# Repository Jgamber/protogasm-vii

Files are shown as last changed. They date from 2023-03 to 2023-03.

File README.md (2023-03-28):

# Protogasm VII
Version two includes code refactoring, and bug fixes.
I have also fixed up the STL models.
- Added encoder knob model for printing
- Cleaned up SCAD Code
- The print time has been reduced by about half
- Removed the screw holes (Lid snaps on now)
- Made the roof/floor less thick
- Removed extra lip around encoder knob hole
- Arduino fits better
- Pressure sensor fits better, USB and power jack holes removed, as they are not used in the case.

Software and hardware for Arduino-based orgasm prediction / detection ... on protoboard!

The nogasm is an amazing toy.  I wanted to make something easier to hack and more accessible to the homebuilder.  Fortunately headcrabned was kind enough to open source the whole thing.

I ported it the Arduino Uno, and hacked around on perfboard until I had it working.  It works great and only requires a handful of readily available through-hole components.

Some aspects have been simplified compared to the original electronics:
* The DIP switches have been eliminated.  Options are configured in the source instead.
* The RGB backlit rotary encoder has been replaced with a more common unlit one.  The mode is still visible on the LED ring.
* It has more LEDs!  NeoPixel Rings with 24 LEDs are the right size for the project.

## Getting started

* [RTFM](User%20Guide.pdf)

* [Buy the parts](BOM.md)
* [Build the control board](pcb/)
* Flash the Arduino with the [Protogasm VII Code](code/protogasm_vii.ino)
* [Print the case](case/)
* [Build the vibrator](vibrator/)
* *TODO* Setup the plug

#### Fine print
This work is licensed under a Creative Commons Attribution-NonCommercial 4.0 International Licence, available at http://creativecommons.org/licenses/by-nc/4.0/.

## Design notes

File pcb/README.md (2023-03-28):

# Circuit Assembly

protogasm_layout.png shows how I build my boards - the wire goes into the hole
next to a component's leg and is then bent down to meet the leg.

Cut the mounting tabs off of the rotary encoder and install it at the center of
the board.  The center pin should point at Arduino pin 12.  Squeeze the pins
together slightly so they go into columns 8 and 13.

The trimpot goes with its center leg directly connected to the AREF hole.

The MOSFET goes on the back of the board on column 12.  The center pin should be
aligned with VIN.

The pressure sensor is installed with the pins bent the wrong way.  If you
install it the right way there isn't enough clearance for the hose barb.  Pin 1
(notched) goes in column 9, two holes up from the SCL pin.  The mounting ears
need to be removed to provide clearance for the USB and power connectors on the
Arduino.  I simply clipped them off with wire cutters.

Install the remaining passives and wiring.

Break away some pin headers to the correct lengths and install them onto the shield (perfboard)
with the short end poking above. Mount it into the Arduino, and solder the top of each pin.

The Neopixel Ring is installed/elevated on three .100 breakaway header pins for PWR, GND,
and OUT.  Do not install a pin header on IN because it will short against the USB port. (The perfboard
touches the metal on the Arduino's USB port.) I soldered a wire to IN and have the other end simply fit
into pin 10, so I can still remove the ring when needed.
The pins need to tilt slightly so place the Neopixel Ring on them to hold them
in the correct orientation before soldering them to the board.

The power out to the motor is taken from either side of the diode.  I made a
short cable with a female power jack DC connector and soldered it to the pins.
Then on the other end of the vibrator a male power jack adapter.

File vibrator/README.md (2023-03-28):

The "handle.STL" and "head.STL" are the main parts of the vibrator, ready for
3D printing.

The vibrator is made from a Mabuchi RS-555PH motor, with an eccentric mass
pressed onto the shaft. These can be purchased pre-assembled, or built from the
motor and some .88" to 1" diameter cylindrical brass stock.

The vibrator case is compatible with attachments designed for the Hitachi Magic
Wand. The motor is press-fit or glued into the two halves of the case.

* Print the case.
* Install an eccentric weight on the motor's shaft if it does not have one already.
* Solder or crimp wires to the motor.
* Pull wires through the small hole in the side of the housing.
* Press firmly to assemble.

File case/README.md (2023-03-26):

Print the case in a light color so that the LEDs show through.

Place the Arduino in the case, and a power jack adapter on the right side of it
inside of the case, and super glue or hot glue it in place. The center hole is for the
pressure sensor, the right hole is for the external power jack (NOT the Arduino's built in)

For the vibrator you can make it easily detachable by using a male/female combo of 
adapters from the Amazon link in the BOM. For example: attach a male adapter to wires coming
out of the vibrator, then solder a female adapter to VIN and GND in the case.

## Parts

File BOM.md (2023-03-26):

| Part | Value | Description | Price  | Mouser | Link |
| ---- | --- | --- | --- | --- | --- |
| ACC  | Arduino UNO | ELEGOO UNO R3 Board ATmega328P | $16.99 | | https://www.amazon.com/dp/B01EWOE0UU  |
| ACC  | Wire Kit | 22 Gauge Wire Solid Core Hookup Wires | $12.99 | | https://www.amazon.com/dp/B088KQFHV7  |
| ACC  | Pin Headers | Male Header Pin, 40 Pin Header Strip | $4.99  | | https://www.amazon.com/dp/B07PKKY8BX  |
| ACC  | DC Adapter | DC 12V 5A Power Supply | $9.89  | | https://www.amazon.com/dp/B08C594VNP  |
| ACC  | DC Cable | DC Power Cable 12V 5A Plugs Male Female | $9.29  | | https://www.amazon.com/dp/B07C7VSRBG  |
| | | | | | |
| VBRT | Vibrator Motor | Mabuchi RS-555 12VDC Motor | $22.95 | | https://www.ebay.com/itm/274750329308 |
| | | | | | |
| PLUG | Air line | Air line 5/32" with Tee | $21.37 | | https://maustec.io/products/replacement-air-line |
| | | | | | |
| -- | NEOPIXEL RING  | Adafruit 24 RGB LED Neopixel Ring | $18.18 | | https://www.amazon.com/dp/B00K9M3WXG  |
| U1 | ARDUINOR3PERF  | Electronics Salon Arduino Uno R3 Perfboard | $14.00 | | https://www.amazon.com/dp/B01J1KM3RM  |
| C1 | 0.1u | CAPACITOR, American symbol | $9.99  | 80-C320C104K5R | https://www.amazon.com/dp/B094HRK8QX  |
| D1 | 1N5818-B | 1.0A SCHOTTKY BARRIER RECTIFIER | $9.99  | 512-1N5818 | https://www.amazon.com/dp/B07YG8K1R9  |
| PS1  | MPX5050GP | Integrated Silicon Pressure Sensor | $53.70 | 841-MPX5050GP | https://www.amazon.com/dp/B005T5KNDK  |
| Q1 | FQP30N06L | Power MOSFET N-Channel | $8.89  | 512-FQP30N06L | https://www.amazon.com/dp/B07WHSD3GJ  |
| R1 | 100K | RESISTOR, American symbol | $12.99 | 660-MF1/4DC1003F | https://www.amazon.com/dp/B07P3MFG5D  |
| SW1  | Rotary encoder | Rotary Encoder w/ switch (EC12D or similar)  | $11.99 | 652-PEC11R-4115F-S18 | https://www.amazon.com/dp/B0197X1UZY  |
| TM1  | 10K | Trimmer Potentiometer | $7.16  | 652-3306P-1-103 | https://www.amazon.com/dp/B00SWK15KE  |

The whole assembly (Including Arduino, accessories, etc) will cost you about **$240.0**

If you already have an Arduino, pin headers, etc, you can get this quite a bit cheaper.

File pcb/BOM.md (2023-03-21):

| Part | Value | Description | Price  | Mouser | Link |
| ---- | --- | --- | --- | --- | --- |
| ACC  | Arduino UNO | ELEGOO UNO R3 Board ATmega328P | $16.99 | | https://www.amazon.com/dp/B01EWOE0UU  |
| ACC  | Wire Kit | 22 Gauge Wire Solid Core Hookup Wires | $12.99 | | https://www.amazon.com/dp/B088KQFHV7  |
| ACC  | Fun Kit | ELEGOO Upgraded Electronics Fun Kit | $17.99 | | https://www.amazon.com/dp/B09YRJQRFF  |
| ACC  | Vibrator Motor | Mabuchi RS-555PH 12VDC Motor | $9.60  | | https://www.ebay.com/itm/285149714808 |
| ACC  | DC Adapter | DC 12V 5A Power Supply | $11.99 | | https://www.amazon.com/dp/B01GEA8PQA  |
| | | | | | |
| PLUG | Air line | Air line 5/32" with Tee | $21.37 | | https://maustec.io/products/replacement-air-line |
| | | | | | |
| -- | NEOPIXEL RING  | Adafruit 24 RGB LED Neopixel Ring | $18.18 | | https://www.amazon.com/dp/B00K9M3WXG  |
| U1 | ARDUINOR3PERF  | Electronics Salon Arduino Uno R3 Perfboard | $14.00 | | https://www.amazon.com/dp/B01J1KM3RM  |
| C1 | 0.1u | CAPACITOR, American symbol | $9.99  | 80-C320C104K5R | https://www.amazon.com/dp/B094HRK8QX  |
| D1 | 1N5818-B | 1.0A SCHOTTKY BARRIER RECTIFIER | $9.99  | 512-1N5818 | https://www.amazon.com/dp/B07YG8K1R9  |
| PS1  | MPX5050GP | Integrated Silicon Pressure Sensor | $53.70 | 841-MPX5050GP | https://www.amazon.com/dp/B005T5KNDK  |
| Q1 | FQP30N06L | Power MOSFET N-Channel | $8.89  | 512-FQP30N06L | https://www.amazon.com/dp/B07WHSD3GJ  |
| R1 | 100K | RESISTOR, American symbol | $12.99 | 660-MF1/4DC1003F | https://www.amazon.com/dp/B07P3MFG5D  |
| SW1  | Rotary encoder | Rotary Encoder w/ switch (EC12D or similar)  | $11.99 | 652-PEC11R-4115F-S18 | https://www.amazon.com/dp/B0197X1UZY  |
| TM1  | 10K | Trimmer Potentiometer | $7.16  | 652-3306P-1-103 | https://www.amazon.com/dp/B00SWK15KE  |

The whole assembly (Including Arduino, accessories, etc) will cost you about **$275.0**

If you already have an Arduino, pin headers, etc, you can get this quite a bit cheaper.

The "Electronics Fun Kit" contains many unnecessary parts, but it includes pin headers, and extra
resistors and useful parts. There is also a 10k trimpot you can use (I used this, but had to cut a hole
in the lid because it is too tall.)

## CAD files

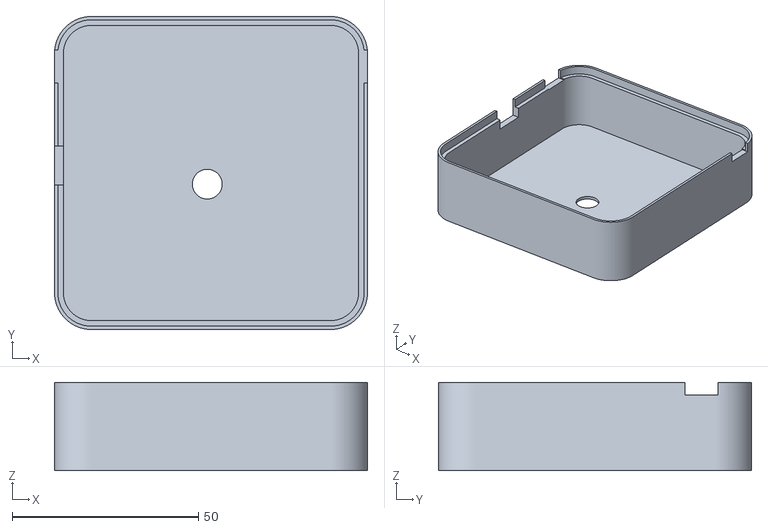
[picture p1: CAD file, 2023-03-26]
case/stl/protogasm_lid.stl
84.1 x 84.1 x 23.7

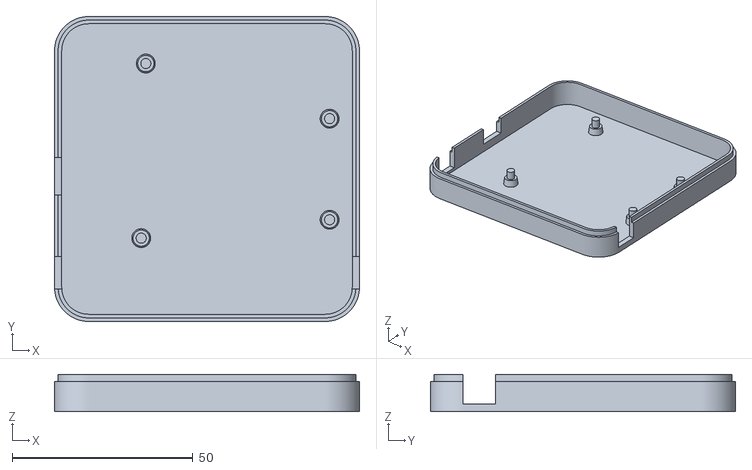
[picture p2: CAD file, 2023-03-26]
case/stl/protogasm_base.stl
84.3 x 84.3 x 10.3

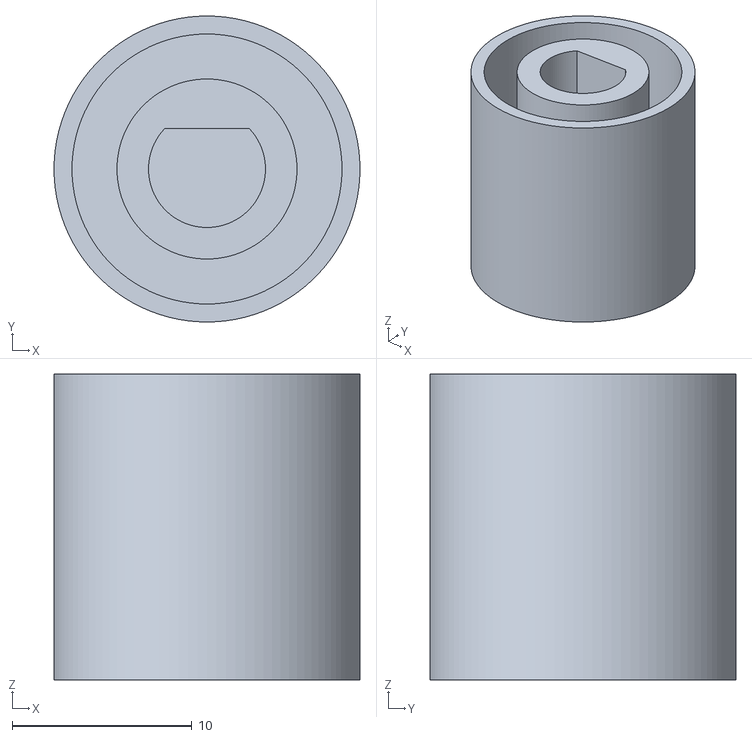
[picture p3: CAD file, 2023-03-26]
case/stl/knob.stl
17.0 x 17.0 x 17.0

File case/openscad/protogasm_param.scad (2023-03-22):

//  ----------------------------------------------------------------------- LICENSE
//  This "3D Printed Case for Arduino Uno, Leonardo" by Zygmunt Wojcik is licensed
//  under the Creative Commons Attribution-ShareAlike 3.0 Unported License.
//  To view a copy of this license, visit
//  http://creativecommons.org/licenses/by-sa/3.0/
//  or send a letter to Creative Commons, PO Box 1866, Mountain View, CA 94042, USA.


//------------------------------------------------------------------------- SHARED PARAMETERS
$fn=100; // resolution

circleD = 21; // round corner circle diameter
roundR = circleD/2; // round corner circle radius
triangleH = (sqrt(3)*(circleD))/2; // triangle height to calculate other variables

layerHeight = 0.25; // some variariables are multiple of layer height and width
layerWidth = 0.5;

verConnectionHoleR = 1.2; // screw thread hole radius
screwHead = 6; // screw head hole diameter

gap = layerHeight/2;

floorHeight = 1.0; // 6*0.25 layer + 0.3 first layer

height = 20.6; // case height
innerHeight = height - floorHeight*2;

pillarSize = 3.0; // corner pillar size

// dimensions of minkowski's inner square
// these are NOT case dimensions
// to calculate external case dimesions add 2 * roundR
// 55.3 + (2*10.5) = 76.3
width = 65.3;
wide = 65.3;

blockLockSize = 2; // middle connection lock size

// side cutting panels size
sidePanelXWidth = wide;
sidePanelYWidth = width;

// prints dimensions of the case
echo("width", width + roundR*2); // total width
echo("wide", wide + roundR*2); // total wide

// UNO PCB dimensions
pcbWide=43.3;
pcbLenght=68.58;
pcbHeight=1.64;
usbHolePosition=38.1;
usbHeight=10.8 + 2;
usbWide=11.43 + 2;
powerJackPosition=7.62;
powerJackWide=8.9;
powerJackHeight=10.8 + 2;

pcbPositionX = (width/2 + roundR - layerWidth*7 - gap*4)-7;
pcbPositionZ = 2.5;

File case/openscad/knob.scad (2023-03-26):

/*
 Simple knob for rotary encoder.
*/
$fn = 100;

height = 17;
diameter = 17;
thickness = 2;
push_btn = 6;
d_shaft_diameter = 6.5;
d_width = 1;


// Outer wall
difference() {
    // ADD
    union() {
        cylinder(height, diameter / 2, diameter / 2);
    }

    // SUBTRACT
    union() {
        translate([0, 0, 1])
        cylinder(height + 0.01, (diameter / 2) - (thickness / 2), (diameter / 2 )- (thickness / 2));
    }
}

// Inner wall
difference() {
    // ADD
    union() {
        dia = d_shaft_diameter - 1.5;
        cylinder(height, dia, dia);
    }
    
    // SUBTRACT
    union() {
        translate([0, 0, push_btn + 0.01])
        cylinder(height - push_btn, d_shaft_diameter / 2, d_shaft_diameter / 2);
    }
}
  
    

// Add shaft holder
union() {
    translate([-d_shaft_diameter / 2, d_shaft_diameter / 2 - d_width, 0])
    cube([d_shaft_diameter, d_width, height]);
}

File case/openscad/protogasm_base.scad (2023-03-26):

//  ----------------------------------------------------------------------- LICENSE
//  This "3D Printed Case for Arduino Uno, Leonardo" by Zygmunt Wojcik is licensed
//  under the Creative Commons Attribution-ShareAlike 3.0 Unported License.
//  To view a copy of this license, visit
//  http://creativecommons.org/licenses/by-sa/3.0/
//  or send a letter to Creative Commons, PO Box 1866, Mountain View, CA 94042, USA.


include <protogasm_param.scad>

//------------------------------------------------------------------------- MODULES
module pcbLeg() {
	translate([0, 0, 0])
	difference() {
		cylinder(h = floorHeight + pcbPositionZ, r1=5.5/2, r2 = 4.5/2);
	}
}


//------------------------------------------------------------------------- MAIN BLOCK
difference() {
	// ADD
	union() {
		// Add Base
		linear_extrude(height = height/2, convexity = 10)
		minkowski() {
			square([width, wide], center = true);
			circle(roundR-1);
		}
	}

	// SUBSTRACT
	union() {
		// Lift floor height
		translate([0, 0, floorHeight]) {
			// Cut Base hole
			linear_extrude(height = height/2, convexity = 10)
			minkowski() {
				square([width, wide], center = true);
				circle(roundR - pillarSize);
			}

			// Cut upper block lock
			difference() {
				translate([0, 0, height/2 - floorHeight - blockLockSize]) {
					cylinder(h = blockLockSize+gap, r=width);
				}

				translate([0, 0, height/2 - floorHeight - blockLockSize - gap*2]) {
					linear_extrude(height = blockLockSize+gap*4, convexity = 10)
					minkowski() {
						square([width, wide], center=true);
						circle(roundR - layerWidth*4);
					}
				}
			}

			// Cut x panels 
			for (i = [0 : 180 : 180])				
			rotate([0, 0, i])
			translate([width/2 + roundR - pillarSize/2 - layerWidth*7, 0, 0]) {
				// Cut X panel hole
				translate([0, 0, height/2])
				cube([pillarSize, sidePanelXWidth, height], center=true);
			}

			// Cut Y panels 
			for (i = [90 : 180 : 270])
			rotate([0, 0, i])
			translate([wide/2 + roundR - pillarSize/2 - layerWidth*7, 0, 0]) {
				// Cut Y panel hole
				translate([0, 0, height/2])
				cube([pillarSize, sidePanelYWidth, height], center=true);
			}
			
            // Cut access holes
			// translate to pcb position
			translate([-pcbPositionX-7, -pcbWide/2-5, pcbPositionZ + pcbHeight]) {
                 // Cut pressure sensor hole
				translate([0, usbHolePosition - usbWide, (usbHeight-2)/2])
				cube([10, usbWide-3, usbHeight], center=true);
                
                // Cut power in hole
                translate([0, -2, (powerJackHeight-6)/2])
                cube([10, powerJackWide, powerJackHeight], center=true);
                
                // Cut power out hole
                translate([pcbLenght + 10, -2, (powerJackHeight-6)/2])
                cube([10, powerJackWide, powerJackHeight], center=true);
			}
		}
	}
}

//------------------------------------------------------------------------- ADD PCB LEGS
// Translate to pcbPositionX	
translate([-pcbPositionX, -pcbWide/2, 0])
difference() {
    // ADD
	union() {
		// Add pcb legs
		for(i=[ [13.97, 2.54, 0], 				
     	    	[15.24, 50.8, 0],
          		[66.04, 35.56, 0],
          		[66.04, 7.62, 0] ]) {
	    		translate(i)
	    		pcbLeg();
		}

		// Add pcb holders
		for(i=[ [13.97, 2.54, 0],
     	    	[15.24, 50.8, 0],
          		[66.04, 35.56, 0],
     	    	[66.04, 7.62, 0] ]) {
			translate(i)
			cylinder(h=floorHeight+pcbPositionZ+3.0, r=1.4);
		}
	}
}

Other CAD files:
case/openscad/protogasm_lid.scad

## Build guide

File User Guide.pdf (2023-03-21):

## Nogasm User Guide

Basic Usage

1. Plug the motor into the right power jack.
2. Plug the power supply into the left power jack.
3. Fit the pressure tubing onto the barb fitting between the power jacks.
4. Connect an inflation bulb and inflatable butt plug to the pressure tubing as shown:

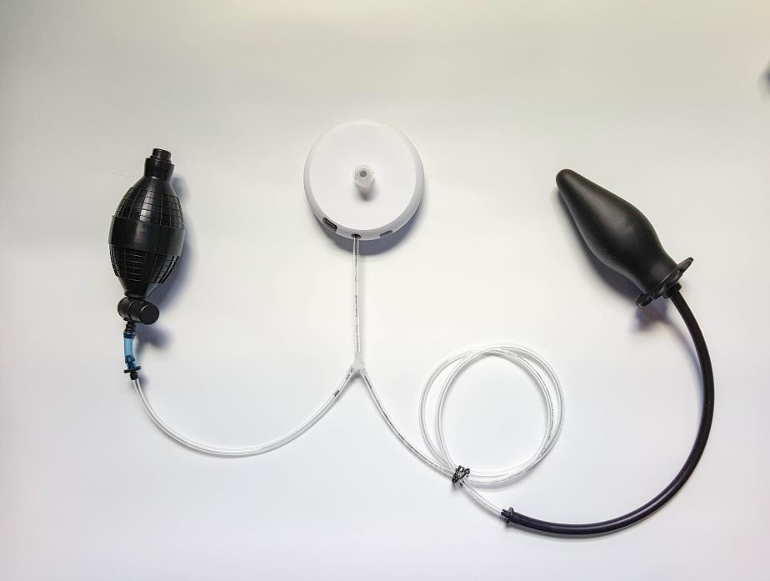
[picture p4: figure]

5. Nogasm detects approaching orgasms from pressure changes in an inflatable butt plug, so to use the edging feature, a user has to wear an at least slightly inflated plug.
6. Set up the vibrator for effective stimulation. Any common “Hitachi Magic Wand” attachment is compatible. If using rope to hold the vibrator in place, the loop in the back, and ridge behind the head of the vibrator can help keep it secure.
7. With the Nogasm on, turn the knob clockwise to check that the vibrator is working. Voluntarily clenching on the inflated plug should show some activity on the LED display at this point.
8. Press the knob once to enable the automated edging mode. The vibrator will slowly ramp up to its maximum speed.
9. The biggest key to a successful edging session is the edging sensitivity setting. Turn the knob clockwise to increase the sensitivity to maximum, and the display will turn from green to red, indicating that the user is too close to orgasm, and the vibrator will turn off temporarily.

10.From there, decrease the sensitivity slowly until you find the correct setting where the vibrator remains on just until the user is close to orgasm. Too high of a sensitivity will keep users from getting very close to orgasm at all, and too low of a sensitivity will allow the vibrator to stay on long enough for a user to cum. Ideal settings vary from person to person, and with different styles of inflatable plugs. If at any point a user is too close to orgasm, the knob can be pressed to immediately turn off the vibrator, and return to manual mode.
11.Finally, the included vibrator is relatively powerful, and lower speeds can feel better than 100% speed. To keep the vibrator at the best feeling speed in automatic mode, press the knob down for 1 second to enter the “Peak Speed” settings menu, which will change the display to all green. Rotating the knob will adjust the maximum speed that the edging mode will ramp up to, and drive the vibrator at that speed to demonstrate. By default, the maximum is set 70%. Long press one more time to return to manual mode.

Control

The Nogasm has one knob that can be rotated or pressed. Pressing the knob will change modes. Each mode illuminates the knob in a specific color, and uses the knob rotation to adjust different settings:

Mode | Knob Color | Knob rotation adjusts:
Manual | Red | Vibrator speed
Automatic Edging | Blue | Edging Sensitivity
Adjust Peak Speed | Green | Maximum vibrator speed in edging mode
Show Pressure Reading | White | [nothing]

Short presses cycle between manual control mode, and automatic edging mode. Long presses (between ½ and 3 seconds) enter the settings menu, which allows you to adjust the maximum speed the vibrator will ramp up to in automatic mode, or visualize raw pressure readings on the LEDs. A very long press (more than 3 seconds) will turn the device off until the knob is pressed again.

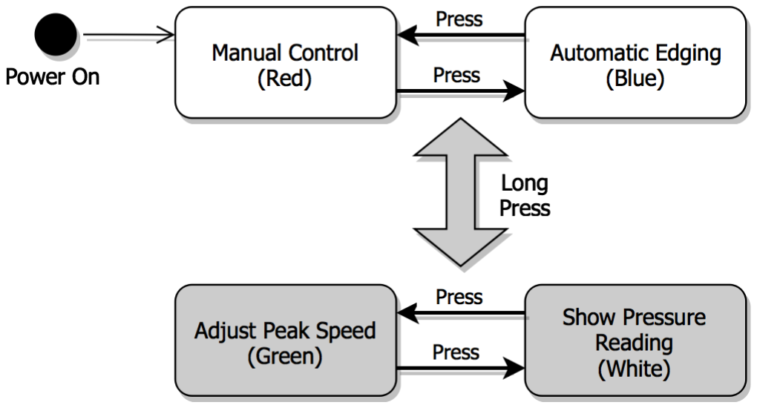
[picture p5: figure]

Troubleshooting

[The motor beeps out 3 high notes when an inflatable plug is inflated or squeezed]

- The 3-high note beep is a warning that the pressure from the inflatable plug is higher than the processor can read. Some plugs require more pressure to inflate, and will cause this issue. When the processor can’t read the pressure correctly, the automatic edging mode will not work.
- You can fix this problem by pulling off the knob and top cover of the Nogasm controller, and using a small screwdriver to manually adjust the pressure sensitivity.
- Turn the controller on, and hold the button down for 1 second to enter the motor speed adjustment menu (green), and then click the knob one time to enter the white “Show Pressure Reading” menu. The white graph directly shows the pressure read by the processor. When the pressure is high enough that the white point moves clockwise all the way to the right, the pressure reading is too high.
- Attach and inflate your plug the desired amount. If the white point now moves to or close to the right side of the controller, the pressure sensitivity should be reduced.
- Reduce the sensitivity by finding the small potentiometer dial, labeled P6 on the top of the circuit board. With a small flathead screwdriver, turn the dial counterclockwise until the lit white point moves near the middle of the scale (the top of the controller). When the plug is squeezed, the pressure should stay low enough that the white marker does not reach the right side of the controller, and the motor no longer beeps the warning code.

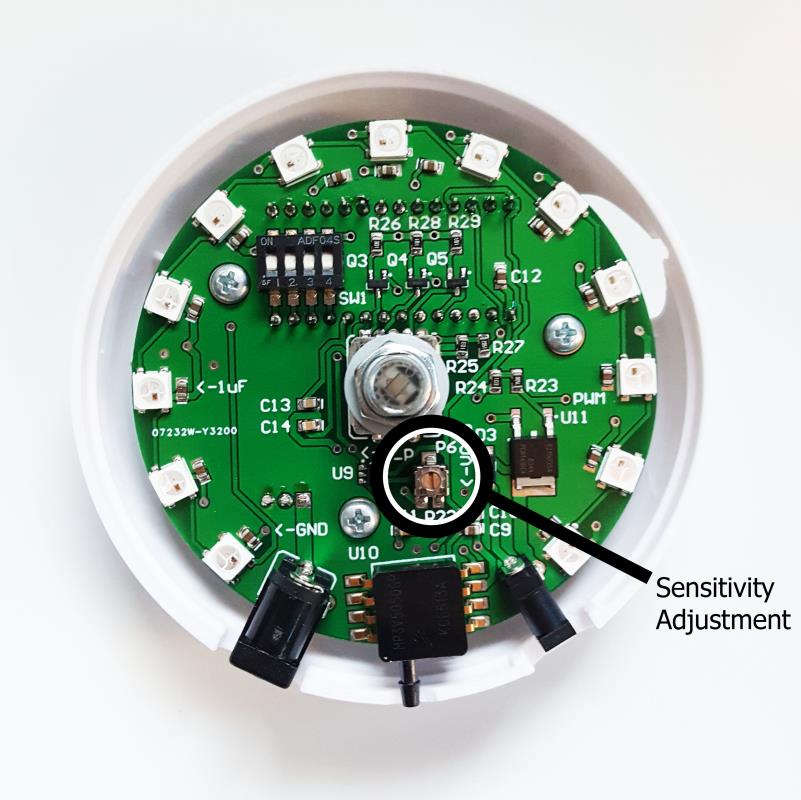
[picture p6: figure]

- The potentiometer adjusts the gain from the pressure sensor to the processor. Ideally, you want the gain (sensitivity) to be as high as it can without causing the 3 beep error. A higher gain makes it easier for the controller to detect orgasms.

Programming

Nogasm was designed to be easy to reprogram or hack for other fun uses. The simplest way to get started is to download the source code from github.com/nogasm/nogasm , and install the Arduino IDE with the Teensyduino add-on, to work with the Teensy-LC that runs Nogasm. The device can be reprogrammed via a Micro-USB cable after removing the programming lid on the bottom of the case.

The Github repository also includes circuit schematics, to make it easy to hack the board, or check if the existing circuitry, like if the 12V PWM motor driver is compatible with other hardware. With just software changes, you could drive a relay to control other toys instead of a vibrator, or even use the pressure sensor and some tubing to make a vibrating alarm clock that doesn’t turn off until it senses you’re out of bed.

USB Datalogging

By default, Nogasm reports its sensor readings and vibrator settings at 60 Hz over a USB virtual serial port at 115200 Baud. The format allows for direct logging to commaseparated variable (.csv) files, or easy visualization using the Arduino IDE’s built-in serial plotter. The format is as follows:

[Vibrator Speed],[Plug Pressure],[25-Second Average Pressure]

Where vibrator speed ranges from 0-255, and the pressures range from 0-4095.

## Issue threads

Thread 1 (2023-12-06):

Case holes don't line up

Miitshii, 2023-12-06:
Hey there! I just blindly printed the case, and only then realised that the holes from the STL don't line up with a standard arduino? Maybe the studs were misplaced?

https://github.com/Jgamber/protogasm-vii/tree/master/case/stl

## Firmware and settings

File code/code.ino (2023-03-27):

// Protogasm (VII) Code, forked from Nogasm Code Rev. 3
// https://github.com/Jgamber/protogasm-vii
/* Drives a vibrator and uses changes in pressure of an inflatable buttplug
 * to estimate a user's closeness to orgasm, and turn off the vibrator
 * before that point.
 * A state machine updating at 60Hz creates different modes and option menus
 * that can be identified by the color of the LEDs
 * 
 * [Red]    Manual Vibrator Control
 * [Blue]   Automatic vibrator edging, knob adjusts orgasm detection sensitivity
 * [Green]  Setting menu for maximum vibrator speed in automatic mode
 * [White]  Debugging menu to show raw data from the pressure sensor ADC
 * [Off]    While still plugged in, holding the button down for >3 seconds turns
 *          the whole device off, until the button is pressed again.
 * 
 * Settings like edging sensitivity, or maximum motor speed are stored in EEPROM,
 * so they are saved through power-cycling.
 * 
 * In the automatic edging mode, the vibrator speed will linearly ramp up to full
 * speed (set in the green menu) over 30 seconds. If a near-orgasm is detected,
 * the vibrator abruptly turns off for 15 seconds, then begins ramping up again.
 * 
 * The LEDs will flash during power on/off, and if the plug pressure rises above
 * the maximum the board can read - this condition could lead to a missed orgasm 
 * if unchecked. The analog gain for the sensor is adjustable via a trimpot to
 * accomidate different types of plugs that have higher/lower resting pressures.
 * 
 * Motor speed, current pressure, and average pressure are reported via USB serial
 * at 115200 baud. Timestamps can also be enabled, from the main loop.
 * 
 * Note - Do not set all the LEDs to white at full brightness at once
 * (RGB 255,255,255) It may overheat the voltage regulator and cause the board 
 * to reset.
 */
//=======Libraries===================================
#include <Encoder.h>
#include <EEPROM.h>
#include "FastLED.h"
#include "RunningAverage.h"


//=======Hardware Setup==============================
//LEDs
#define NUM_LEDS 24
#define LED_PIN 10
#define LED_TYPE    WS2812B
#define COLOR_ORDER GRB
#define BRIGHTNESS 50 //Subject to change, limits current that the LEDs draw

//Encoder
#define ENC_SW   5 //Pushbutton on the encoder
Encoder myEnc(3, 2); //Quadrature inputs
#define ENC_SW_UP   HIGH
#define ENC_SW_DOWN LOW

//Motor (MOSFET gate pin)
#define MOTPIN 9

//Pressure Sensor Analog In
#define PRESSUREPIN A0

// Sampling 4x and not dividing keeps the samples from the Arduino Uno's 10 bit
// ADC in a similar range to the Teensy LC's 12-bit ADC.  This helps ensure the
// feedback algorithm will behave similar to the original.
#define OVERSAMPLE 4
#define ADC_MAX 1023

//=======Software/Timing options=====================
#define FREQUENCY 60 //Update frequency in Hz
#define LONG_PRESS_MS 600 //ms requirements for a long press, to move to option menus
#define V_LONG_PRESS_MS 2500 //ms for a very long press, which turns the device off

//Update/render period
#define period (1000 / FREQUENCY)

//Running pressure average array length and update frequency
#define RA_HIST_SECONDS 25
#define RA_FREQUENCY 6
#define RA_TICK_PERIOD (FREQUENCY / RA_FREQUENCY)
RunningAverage raPressure(RA_FREQUENCY * RA_HIST_SECONDS);

//=======State Machine Modes=========================
#define MANUAL      1
#define AUTO        2
#define OPT_SPEED   3
#define OPT_PRES    4

//=======Button states===============================
#define BTN_NONE   0
#define BTN_SHORT  1
#define BTN_LONG   2
#define BTN_V_LONG 3

//=======EEPROM Addresses============================
#define MAX_SPEED_ADDR    1
#define SENSITIVITY_ADDR  2

//=======Global Variables============================
#define MOT_MAX 255 // Motor PWM maximum
#define MOT_MIN 20  // Motor PWM minimum. It needs a little more than this to start.
#define DEFAULT_PLIMIT 600

const float rampUpTimeSec = 30;

CRGB leds[NUM_LEDS];

uint8_t state = MANUAL;
int pressure = 0;
int avgPressure = 0; //Running 25 second average pressure
int pLimit = DEFAULT_PLIMIT; //Limit in change of pressure before the vibrator turns off
float motSpeed = 0; //Motor speed, 0-255 (float to maintain smooth ramping to low speeds)

// Persisted settings
int maxSpeed = 255; //maximum speed the motor will ramp up to in automatic mode
int sensitivity = 0; //orgasm detection sensitivity, persists through different states


//=======Setup=======================================
void alert(CRGB col) {
  FastLED.setBrightness(10);

  for (int i = 0; i < 3; i++) {
    fill_gradient_RGB(leds, 0, col, NUM_LEDS - 1, col);
    FastLED.show();
    delay(150);
    fill_gradient_RGB(leds, 0, CRGB::Black, NUM_LEDS - 1, CRGB::Black);
    FastLED.show();
    delay(150);
  }

  FastLED.setBrightness(BRIGHTNESS);
}

void setup() {
  pinMode(ENC_SW, INPUT); //Pin to read when encoder is pressed
  digitalWrite(ENC_SW, HIGH); // Encoder switch pullup

  analogReference(EXTERNAL);

  // Classic AVR based Arduinos have a PWM frequency of about 490Hz which
  // causes the motor to whine.  Change the prescaler to achieve 31372Hz.
  //TCCR1B |= (1 << CS10);
  //TCCR1B |= (1 << CS11);
  //TCCR1B |= (1 << CS12);

  pinMode(MOTPIN, OUTPUT); //Enable "analog" out (PWM)

  pinMode(PRESSUREPIN, INPUT); //default is 10 bit resolution (1024), 0-3.3

  raPressure.clear(); //Initialize a running pressure average

  digitalWrite(MOTPIN, LOW); //Make sure the motor is off

  delay(500); // delay for recovery

  Serial.begin(115200);

  FastLED.addLeds<LED_TYPE, LED_PIN, COLOR_ORDER>(leds, NUM_LEDS).setCorrection(TypicalLEDStrip);
  FastLED.setBrightness(BRIGHTNESS);

  //Recall saved settings from memory
  sensitivity = EEPROM.read(SENSITIVITY_ADDR);
  maxSpeed = min(EEPROM.read(MAX_SPEED_ADDR), MOT_MAX); //Obey the MOT_MAX the first power cycle after changing it.
  alert(CRGB::Green); //Power on animation
}

//=======Util Functions=================

//Draw a "cursor", one pixel representing either a pressure or encoder position value
//C1,C2,C3 are colors for each of 3 revolutions over the 13 LEDs (39 values)
void draw_cursor_3(int pos, CRGB C1, CRGB C2, CRGB C3){
  pos = constrain(pos, 0, NUM_LEDS*3-1);
  int colorNum = pos / NUM_LEDS; //revolution number
  int cursorPos = pos % NUM_LEDS; //place on circle, from 0-12

  switch (colorNum) {
    case 0:
      leds[cursorPos] = C1;
      break;
    case 1:
      leds[cursorPos] = C2;
      break;
    case 2:
      leds[cursorPos] = C3;
      break;
  }
}

//Draw a "cursor", one pixel representing either a pressure or encoder position value
void draw_cursor(int pos, CRGB C1){
  pos = constrain(pos, 0, NUM_LEDS - 1);
  leds[pos] = C1;
}

//Draw 3 revolutions of bars around the LEDs. From 0-39, 3 colors
void draw_bars_3(int pos, CRGB C1, CRGB C2, CRGB C3){
  pos = constrain(pos, 0, NUM_LEDS * 3 - 1);
  int colorNum = pos / NUM_LEDS; //revolution number
  int barPos = pos % NUM_LEDS; //place on circle, from 0-12

  switch (colorNum) {
    case 0:
      fill_gradient_RGB(leds, 0, C1, barPos, C1);
      break;
    case 1:
      fill_gradient_RGB(leds, 0, C1, barPos, C2);
      break;
    case 2:
      fill_gradient_RGB(leds, 0, C2, barPos, C3);
      break;
  }
}

//Provide a limited encoder reading corresponting to tacticle clicks on the knob.
//Each click passes through 4 encoder pulses. This reduces it to 1 pulse per click
int encLimitRead(int minVal, int maxVal){
  if (myEnc.read() > maxVal * 4) myEnc.write(maxVal * 4);
  else if (myEnc.read() < minVal * 4) myEnc.write(minVal * 4);

  return constrain(myEnc.read() / 4, minVal, maxVal);
}

//=======Program Modes/States==================

// Manual vibrator control mode (red), still shows orgasm closeness in background
void run_manual() {
  //In manual mode, only allow for 13 cursor positions, for adjusting motor speed.
  int knob = encLimitRead(0, NUM_LEDS - 1);
  motSpeed = map(knob, 0, NUM_LEDS - 1, 0.0, (float)MOT_MAX);
  analogWrite(MOTPIN, motSpeed);

  int presDraw = map(constrain(pressure - avgPressure, 0, pLimit), 0, pLimit, 0, NUM_LEDS * 3);
  draw_bars_3(presDraw, CRGB::Green, CRGB::Yellow, CRGB::Red);
  draw_cursor(knob, CRGB::Red);
}

// Automatic edging mode, knob adjust sensitivity.
void run_auto() {
  static float motIncrement = 0.0;
  motIncrement = ((float)maxSpeed / ((float)FREQUENCY * (float)rampUpTimeSec));

  int knob = encLimitRead(0, (3 * NUM_LEDS) - 1);
  if (sensitivity != knob * 4) // setting updated, save
    EEPROM.update(SENSITIVITY_ADDR, knob * 4);
  sensitivity = knob * 4; //Save the setting if we leave and return to this state
  //Reverse "Knob" to map it onto a pressure limit, so that it effectively adjusts sensitivity
  pLimit = map(knob, 0, 3 * (NUM_LEDS - 1), 600, 1); //set the limit of delta pressure before the vibrator turns off
  //When someone clenches harder than the pressure limit
  if (pressure - avgPressure > pLimit) {
    motSpeed = -.5*(float)rampUpTimeSec*((float)FREQUENCY*motIncrement);//Stay off for a while (half the ramp up time)
  } else if (motSpeed < (float)maxSpeed) {
    motSpeed += motIncrement;
  }

  analogWrite(MOTPIN, motSpeed > MOT_MIN ? (int)motSpeed : 0);

  int presDraw = map(constrain(pressure - avgPressure, 0, pLimit), 0, pLimit, 0, NUM_LEDS * 3);
  draw_bars_3(presDraw, CRGB::Green, CRGB::Yellow, CRGB::Red);
  draw_cursor_3(knob, CRGB(50, 50, 200), CRGB::Blue, CRGB::Purple);
}

//Setting menu for adjusting the maximum vibrator speed automatic mode will ramp up to
void run_opt_speed() {
  int knob = encLimitRead(0, NUM_LEDS - 1);
  motSpeed = map(knob, 0, NUM_LEDS - 1, 0.0, (float)MOT_MAX);
  analogWrite(MOTPIN, motSpeed);
  maxSpeed = motSpeed; //Set the maximum ramp-up speed in automatic mode

  //Little animation to show ramping up on the LEDs
  static int visRamp = 0;
  if (visRamp <= FREQUENCY * NUM_LEDS - 1) visRamp += 16;
  else visRamp = 0;
  draw_bars_3(map(visRamp, 0, (NUM_LEDS - 1) * FREQUENCY, 0, knob), CRGB::Green, CRGB::Green, CRGB::Green);
}

//Simply display the pressure analog voltage. Useful for debugging sensitivity issues.
void run_opt_pres() {
  int p = map(analogRead(PRESSUREPIN), 0, ADC_MAX, 0, NUM_LEDS - 1);
  draw_cursor(p, CRGB::White);
}

//Poll the knob click button, and check for long/very long presses as well
uint8_t check_button() {
  static bool lastBtn = ENC_SW_UP;
  static unsigned long keyDownTime = 0;
  uint8_t btnState = BTN_NONE;
  bool thisBtn = digitalRead(ENC_SW);

  //Detect single presses, no repeating, on keyup
  if (thisBtn == ENC_SW_DOWN && lastBtn == ENC_SW_UP) keyDownTime = millis();
  
  if (thisBtn == ENC_SW_UP && lastBtn == ENC_SW_DOWN) { //there was a keyup
    if ((millis() - keyDownTime) >= V_LONG_PRESS_MS) {
      btnState = BTN_V_LONG;
    } else if ((millis() - keyDownTime) >= LONG_PRESS_MS) {
      btnState = BTN_LONG;
    } else {
      btnState = BTN_SHORT;
    }
  }

  lastBtn = thisBtn;
  return btnState;
}

//run the important/unique parts of each state
void run_state_machine(uint8_t state) {
  switch (state) {
    case MANUAL:
      run_manual();
      break;
    case AUTO:
      run_auto();
      break;
    case OPT_SPEED:
      run_opt_speed();
      break;
    case OPT_PRES:
      run_opt_pres();
      break;
    default:
      run_manual();
      break;
  }
}

//Switch between state machine states, and reset the encoder position as necessary
//Returns the next state to run. Very long presses will turn the system off (sort of)
uint8_t set_state(uint8_t btnState, uint8_t state) {
  if (btnState == BTN_NONE) return state;

  if (btnState == BTN_V_LONG) {
    //Turn the device off until woken up by the button
    Serial.println("power off");
    fill_gradient_RGB(leds, 0, CRGB::Black, NUM_LEDS - 1, CRGB::Black); //Turn off LEDS
    FastLED.show();
    analogWrite(MOTPIN, 0);
    alert(CRGB::Red);
    analogWrite(MOTPIN, 0); //Turn Motor off

    while (digitalRead(ENC_SW)) delay(1);
    Serial.println("power on");
    alert(CRGB::Green);
    return MANUAL;
  } else if (btnState == BTN_SHORT) {
    switch (state) {
      case MANUAL:
        myEnc.write(sensitivity); //Whenever going into auto mode, keep the last sensitivity
        motSpeed = 0; //Also reset the motor speed to 0
        return AUTO;
      case AUTO:
        myEnc.write(0); //Whenever going into manual mode, set the speed to 0.
        motSpeed = 0;
        EEPROM.update(SENSITIVITY_ADDR, sensitivity);
        return MANUAL;

      // Changing between settings pages
      case OPT_SPEED:
        myEnc.write(0);
        EEPROM.update(MAX_SPEED_ADDR, maxSpeed);
        motSpeed = 0;
        analogWrite(MOTPIN, motSpeed); //Turn the motor off for the white pressure monitoring mode
        return OPT_PRES;
      case OPT_PRES:
        myEnc.write(map(maxSpeed, 0, 255, 0, 4 * NUM_LEDS)); //start at saved value
        return OPT_SPEED;
    }
  } else if (btnState == BTN_LONG) {
    switch (state) {
      case MANUAL:
        myEnc.write(map(maxSpeed, 0, 255, 0, 4 * NUM_LEDS)); //start at saved value
        return OPT_SPEED;
      case AUTO:
        myEnc.write(map(maxSpeed, 0, 255, 0, 4 * NUM_LEDS)); //start at saved value
        return OPT_SPEED;
      case OPT_SPEED:
        myEnc.write(0);
        return MANUAL;
      case OPT_PRES:
        myEnc.write(0);
        return MANUAL;
    }
  } else return MANUAL;
}

//=======Main Loop=============================
void loop() {
  static uint8_t state = MANUAL;
  static int sampleTick = 0;

  //Run this section at the update frequency (default 60 Hz)
  if (millis() % period != 0) return;
  delay(1);
  
  // Update avg pressure
  sampleTick++; //Add pressure samples to the running average slower than 60Hz
  if (sampleTick % RA_TICK_PERIOD == 0) {
    raPressure.addValue(pressure);
    avgPressure = raPressure.getAverage();
  }
  
  // Update current pressure
  pressure = 0;
  for(uint8_t i = OVERSAMPLE; i; --i) {
    pressure += analogRead(PRESSUREPIN);
    if (i) {      // Don't delay after the last sample
      delay(1);  // Spread samples out a little
    }
  }

  fadeToBlackBy(leds, NUM_LEDS, 20); //Create a fading light effect. LED buffer is not otherwise cleared
  uint8_t btnState = check_button();
  state = set_state(btnState, state); //Set the next state based on this state and button presses
  run_state_machine(state);
  FastLED.show(); //Update the physical LEDs to match the buffer in software

  //Alert that the Pressure voltage amplifier is railing, and the trim pot needs to be adjusted
  if (pressure > 4030) alert(CRGB::DarkOrange); // Flash red

  //Report pressure and motor data over USB for analysis / other uses. timestamps disabled by default
  //Serial.print(millis()); //Timestamp (ms)
  //Serial.print(",");
  Serial.print(motSpeed); //Motor speed (0-255)
  Serial.print(",");
  Serial.print(pressure); //(Original ADC value - 12 bits, 0-4095)
  Serial.print(",");
  Serial.println(avgPressure); //Running average of (default last 25 seconds) pressure
}

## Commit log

2023-03-21 Update BOM
2023-03-21 Update assembly notes
    [finishing jig.STL]
2023-03-22 Fix 3D printed case
    [protogasm_base.scad, protogasm_base.stl, protogasm_lid.scad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]
2023-03-22 Update BOM to reflect fixed case
2023-03-22 Fix lid model
    [protogasm_lid.scad, protogasm_lid.stl]
2023-03-26 Add encoder knob 3d print
    [knob.scad, knob.stl, protogasm_lid.scad]
2023-03-26 Add power out hole to case
    [protogasm_base.scad, protogasm_base.stl, protogasm_lid.scad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]
2023-03-27 Code bug fixes Motor not working
    [code.ino]
